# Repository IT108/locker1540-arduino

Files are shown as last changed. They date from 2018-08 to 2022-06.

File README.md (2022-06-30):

# Система контроля и управления доступом
## Проект в школе ОРТ 1540 

<ins>Амеличев Константин, Парамонов Дмитрий, под руководством Скибицкого Романа Марковича</ins>

Состоит из нескольких компонент:

* Ардуино-контролер, использующийся для управления различными модулями
* RFID сканер карточек (коридор)
* Трехцветный светодиод для индикации состояния сканера (коридор)
* Кнопка звонка (коридор)
* Электромагнитный замок
* Датчики состояния двери (открыта/закрыта, герконы)
* Пьезоэлемент для звука звонка в дверь
* Кнопка открытия двери изнутри кабинета
* Датчики движения в кабинете
* Источник бесперебойного питания
* Реле для управления освещением
* Внешняя индикация для кабинета охраны
* Веб-сервер на Raspberry Pi, хранящий базу данных о пришедших пользователях
* Динамик для персональных приветствий

### Функционал:

* Вход в кабинет по корректным карточкам
* Аудиоприветствие вошедшего человека (например, "Добрый день, Роман"). Конструируется случайно, дополнительно учитывая время суток
* Мониторинг наличия людей в кабинете, выключение света при отсутствии людей
* Кнопка звонка, играющая мелодию из "Звездных войн"
* Отправка состояния системы на индикационную панель охранника

## Фотографии, схемы:

Одна из версий платы:
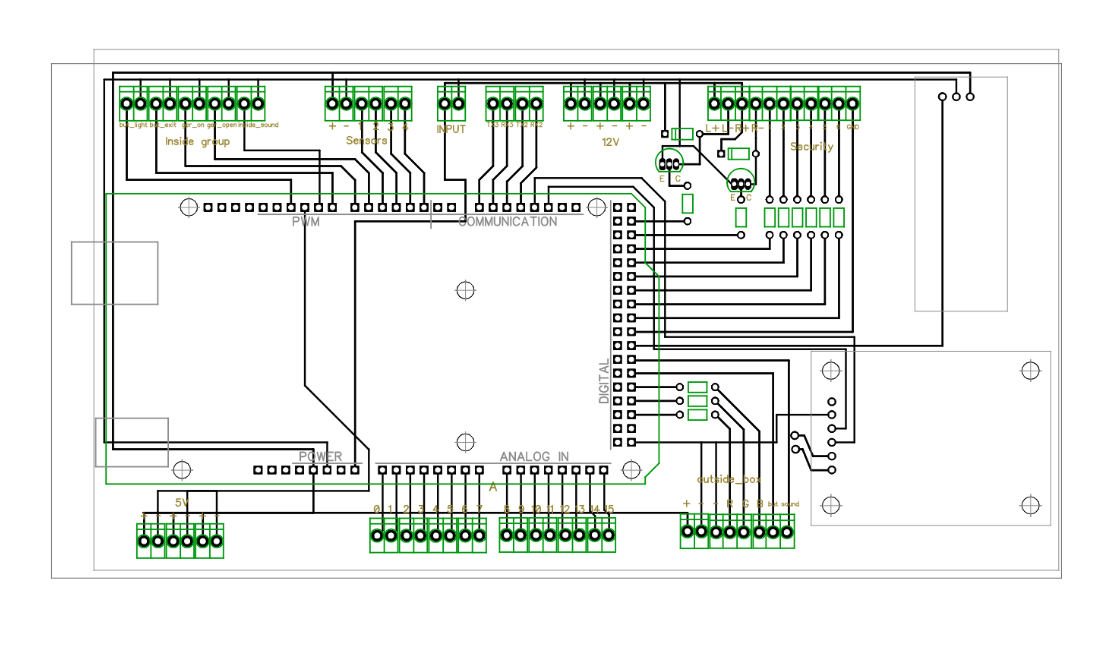
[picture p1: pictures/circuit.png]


Физическая спаянная плата с Arduino и реле
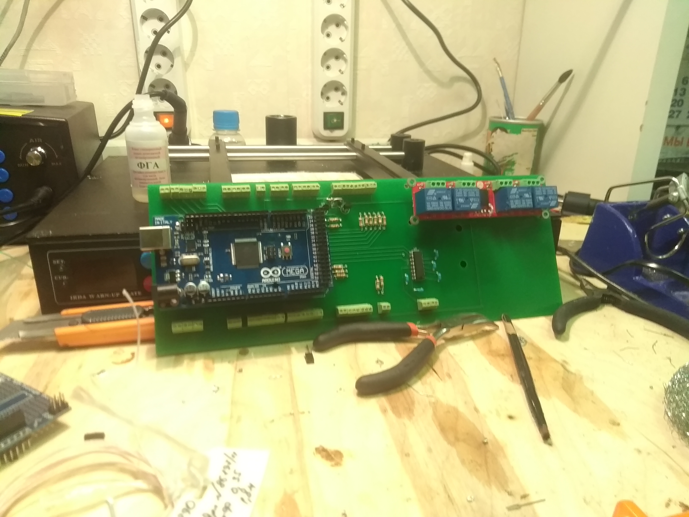
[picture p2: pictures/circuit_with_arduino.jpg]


Демонстрация зеленого светодиода при прикладывании нужной карты
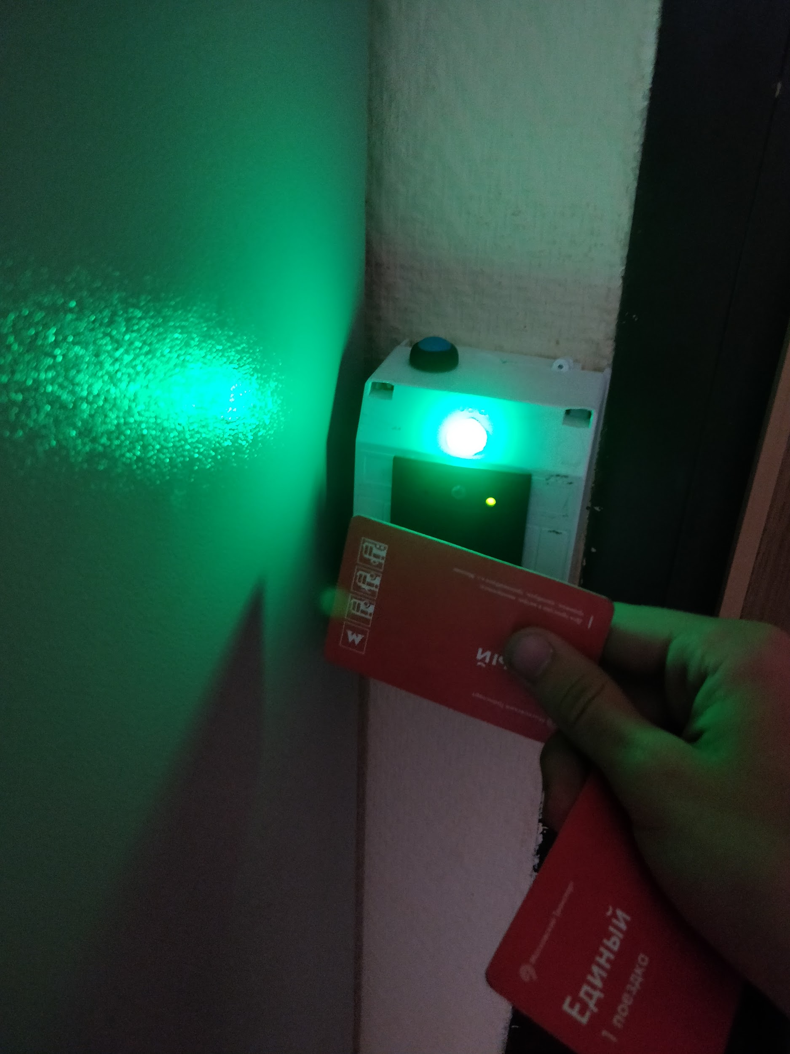
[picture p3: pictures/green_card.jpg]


Интеграция в кабинет до 2018 года (без собственной платы, arduino + COM-shield)
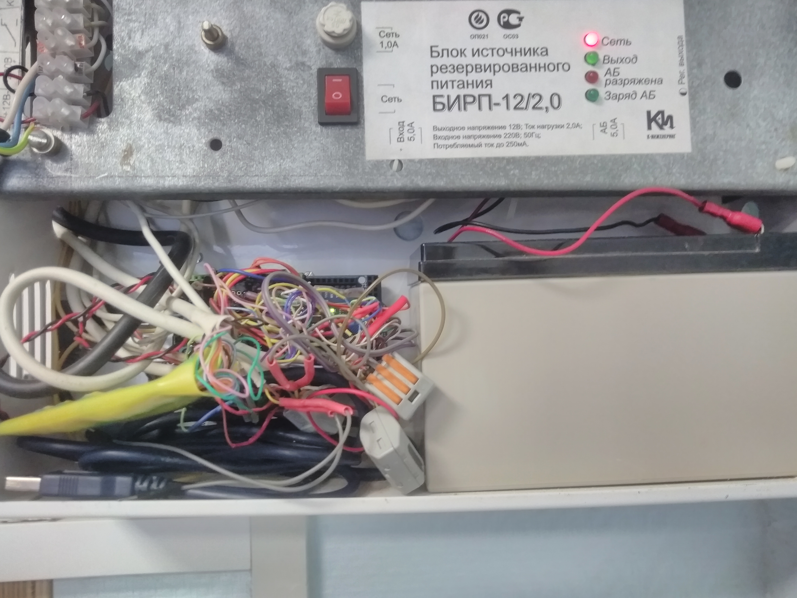
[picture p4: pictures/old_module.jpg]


Интеграция в кабинет 2018/2019 года (а собственной платой, arduino + RS232-модуль + реле) 
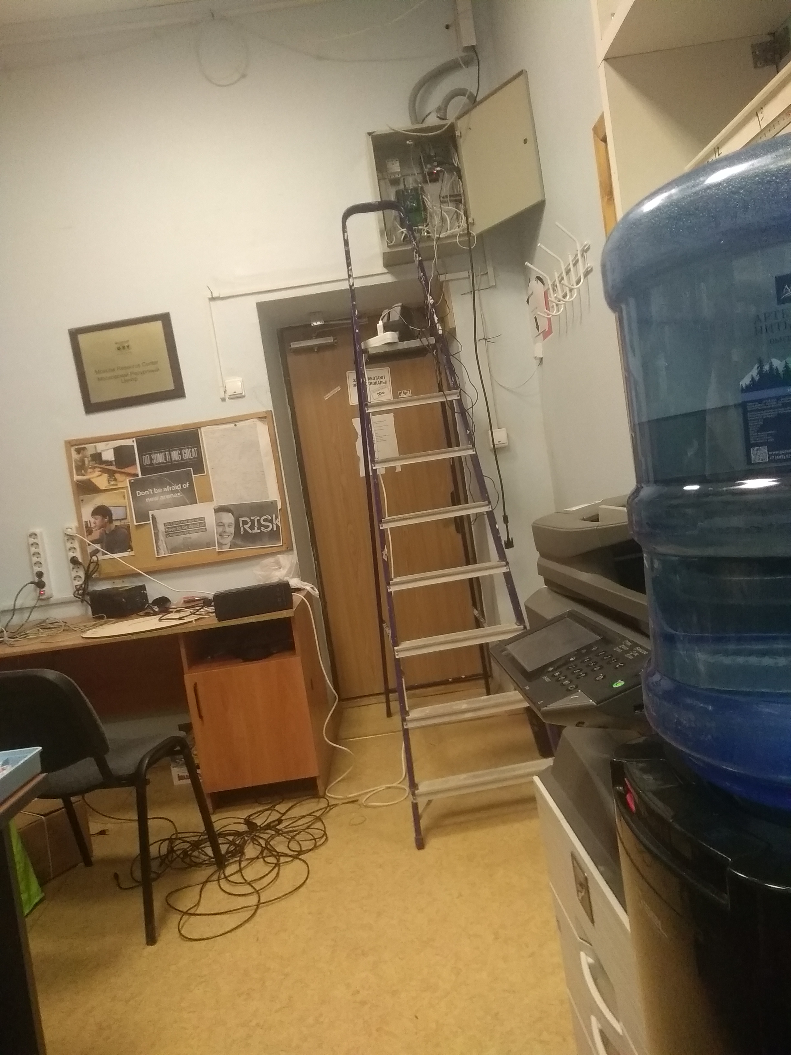
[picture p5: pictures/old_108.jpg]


Интеграция в кабинет с 2019/2020 учебного года


## Интересные документы:
* Текст проектной работы по мотивам проекта [link](МГК%20ЗАМОК%202019.pdf)
* Необходимые детали для сбора аналогичной платы [link](schemes/Список%20покупок%20для%20новой%20платы.xlsx)
* Схема соединений между блоками системы [link](schemes/locker108scheme.pdf)

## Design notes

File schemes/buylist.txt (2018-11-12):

что надо купить

Шкаф для хранения системы
Raspberry Pi для сервера
ИБП компактный

тезисы - 
сверху ставим Din, на который крепим автомат, raspberry pi
внизу ставим большой ups
По центру ставим еще один din, на который повесим плату
Надо тянуть один провод ethernet

https://videoglaz.ru/elektromontazhnye-shkafy-i-schity/ruself/ruself-schmp-06-ip31

https://www.moxa.ru/shop/accessories/mounting/dk35a/

https://www.etm.ru/cat/nn/9724561/ х2

http://amperka.ru/collection/bestsellers/product/raspberry-pi-3-model-b-plus

http://lartmaster.ru/goods/Plastikovye-derzhateli-dlya-DIN-rejki

https://www.dns-shop.ru/product/940e53a73bcf3330/ibp-dexp-iec-450va/characteristics/

https://on.pleer.ru/product_219638_Sven_Special_Base_5_Sockets_05m.html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

Вариант 2 http://www.mean-well.ru/store/DRC-60A/

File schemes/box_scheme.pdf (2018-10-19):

автомат arduino + raspberry pi

2ая din- рейка

UPS

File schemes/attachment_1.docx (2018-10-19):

Инструкция по открытию двери

С левой стороны от двери находится считыватель карт.

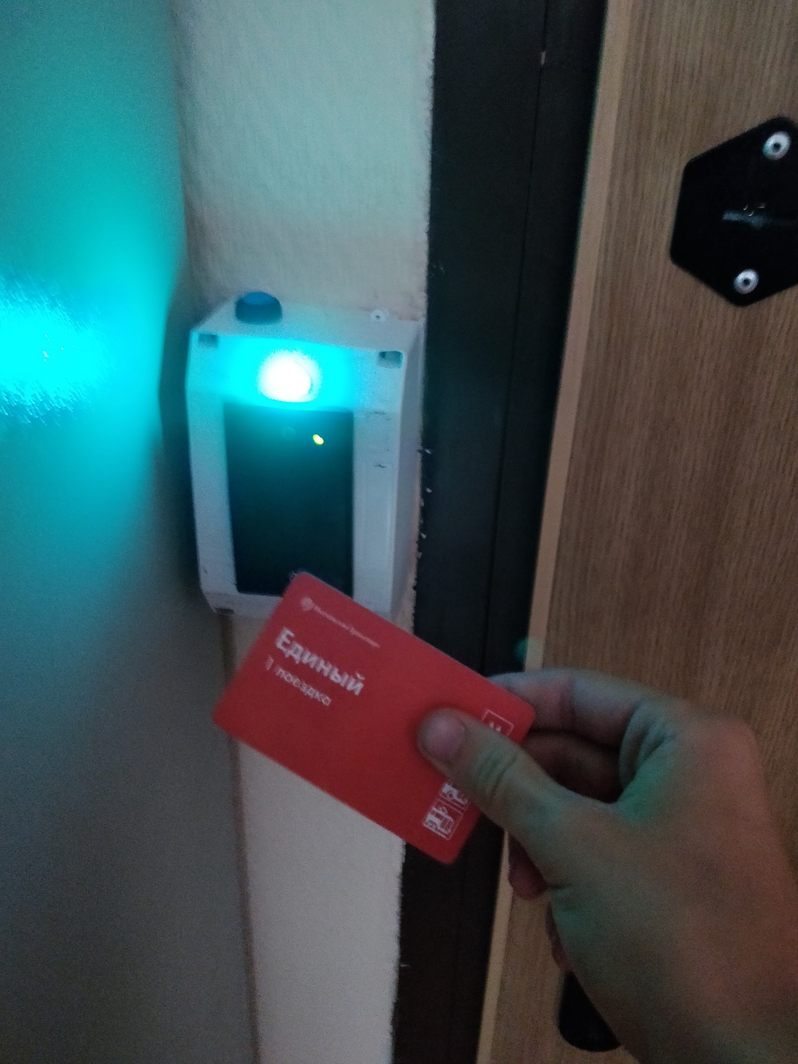
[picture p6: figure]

Для того, чтобы открыть дверь, надо приложить свою карту к считывателю и дождаться звукового сигнала, который означает, что карта считалась. Далее возможно несколько ситуаций, которые зависят от того, есть ли карточка в базе данных(допущена к входу) или нет.

1. Карточка есть в базе данных. Тогда светодиод над считывателем загорается зеленым цветом и дверь открывается.


2. Карточки нет в базе данных. Тогда светодиод над считывателем загорается красным цветом.

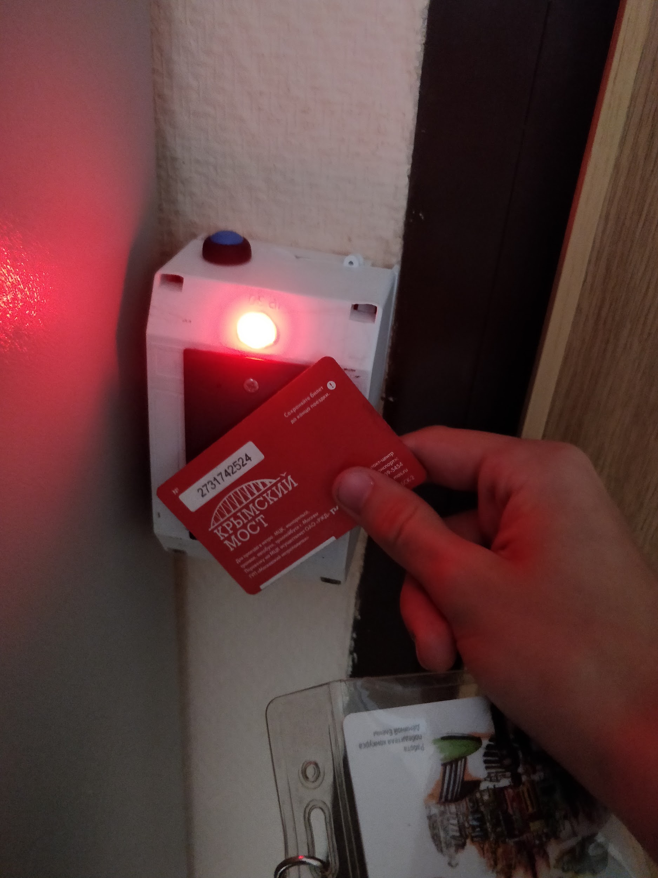
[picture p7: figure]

3. Карточка является мастер-картой. Тогда светодиод над считывателем загорается синим цветом.

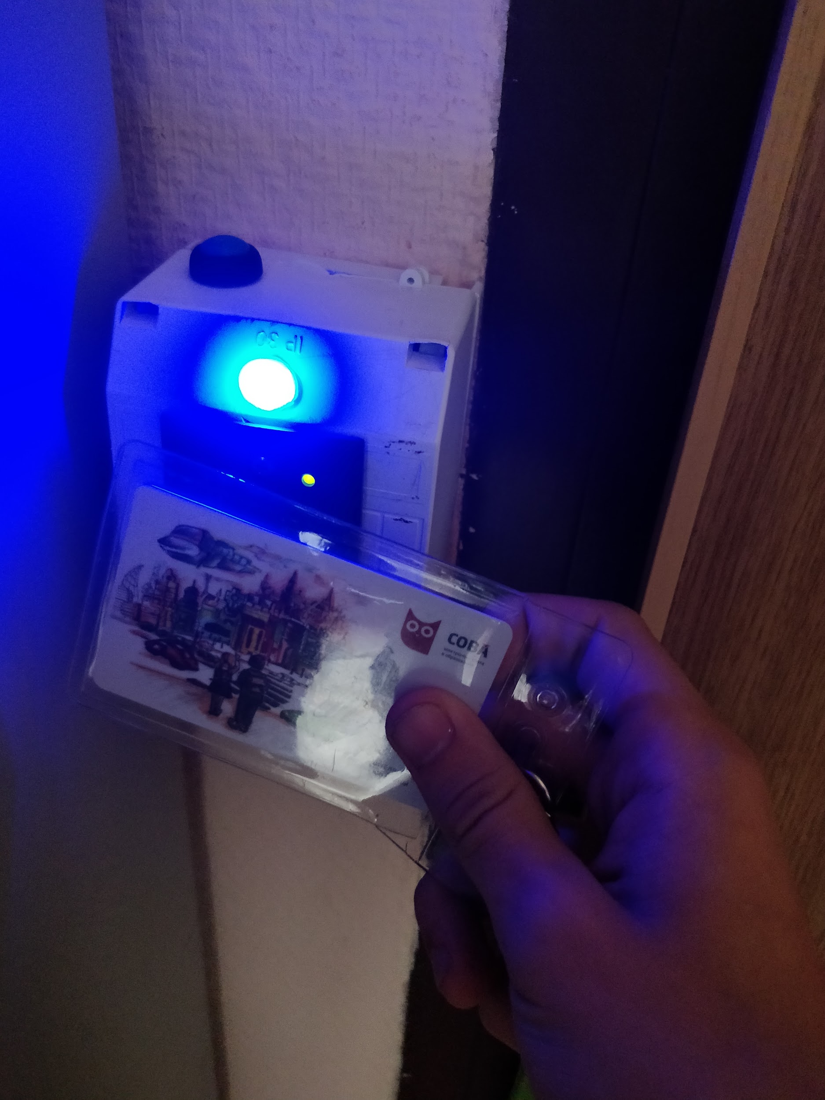
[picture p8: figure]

Для того, чтобы выйти из кабинета, надо нажать на кнопку выхода, расположенную с правой стороны относительно двери.

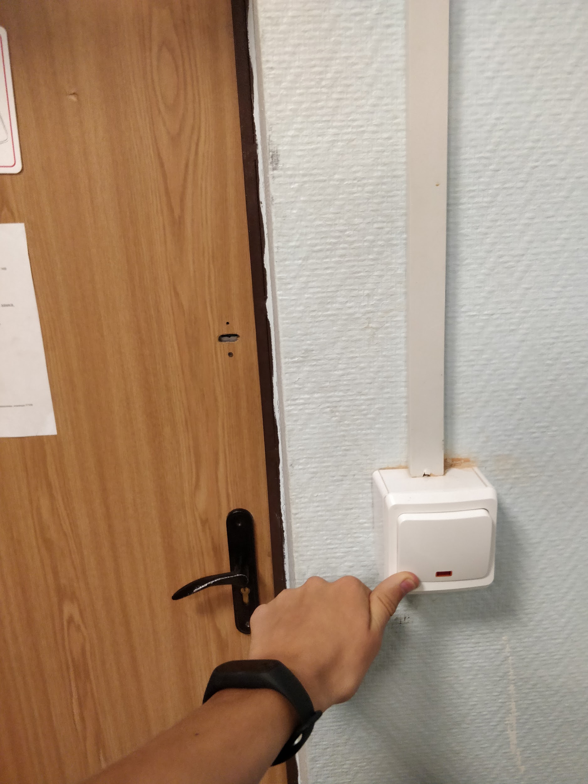
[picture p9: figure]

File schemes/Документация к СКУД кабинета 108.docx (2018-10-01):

Документация к СКУД кабинета 108

1. Функционал системы
  1) Вход-выход из кабинета
  2) Система работы с ключ-картами
  3) Функционал на вахте
  4) Музыкальная шкатулка
2. Физическая часть
  1) Основной блок
    a. Управляющий контроллер
    b. Плата управлением питания системы
  2) Перечень внешних блоков
  3) Соединение внешних блоков
  4) Запирающее устройство
  5) Система электропитания
3. Софтверная часть
  1) Контроллер замка
  2) Веб-сервер
4. Приложение

Функционал системы

Вход-выход из кабинета

В режиме ожидания дверь кабинета находится в закрытом состоянии. Вход в кабинет осуществляется с помощью ключ-карты. Для выхода из кабинета необходимо воспользоваться возвратным выключателем внутри кабинета. В случае, если у поситителя нет доступа в кабинет, он может воспользоваться кнопкой звонка. [ТУДУ. Полноценная инструкция по использованию модуля «дверь» находится в Приложение 1(Инструкция по входу-выходу из кабинета). При возникновении внештатных ситуаций в кабинет можно попасть, воспользовавшись инструкцией из Приложение 2(Инструкция по аварийному открытию кабинета)]

Система работы с ключ-картами

Для аунтификации используются ключ-карты, соответствующие стандарту Mifare RFID. Для модификации списка людей с доступом в кабинет можно использовать приложение или мастер-карту. При использовании приложения предоставляется возможность дополнять учетную запись дополнительными параметрами(ФИО, приветствие итд), поэтому такой способ является предпочтительным. Для моментального добавления учетной записи воспользуйтесь мастер-картой. При добавлении учетной записи с помощью мастер-карты рекомендуется дополнительно установить параметры учетной записи через приложение.

[ТУДУ. Для изменения базы допущенных людей пользуйтесь Приложение 3. Инструкция по добавлению-удалению людей c помощью веб-консоли. или Приложение 4. Инструкция по добавлению-удалению людей с помощью мастер-карты]

Функционал на вахте

Для осуществления контроля состояния кабинета сотрудниками службы безопасности предусмотрена мониторинговая система, которая позволяет отслеживать:

1. Отсутствие людей в кабинете – зеленая индикация соответствует пустому кабинету, а красная – наличию людей.
2. Состояние двери – зеленая индикация соответствует закрытой двери, а красная - открытой.
3. Состояние защелки – зеленая индикация соответствует катушке защелки под напряжением, а красная – обесточенной.

Музыкальная шкатулка

Система имеет возможность проигрывать аудиофайлы, загруженные в память. В данный момент эта функция используется для проигрывания приветствия при входе пользователя в кабинет. Управление устройством осуществляется с платы веб-сервера. Для создания персонализированного приветствия предусмотрен отдельный функционал. [ТУДУ. Приложение 5. Инструкция по работе с аудиофайлами]

Физическая часть

Основной блок

Управляющий контроллер

В качестве основного контроллера используется Arduino Mega ADK. Дополнительно на нее установлен RS232 Shield для взаимодействия со считывателем ключ-карт.

К основному контроллеру подсоединены:

1. Внешний модуль «Считыватель»
2. Внешний модуль «Замок», имеется размыкатель питания в модуле «Считыватель»
3. Внешний модуль «Веб-сервер»
4. Модуль «Звонок», расположенный в основном блоке
5. Внешние модули «Датчики движения»
6. Внешний модуль «Мониторинговая система»
7. Внешний модуль «Кнопка выхода»
8. Внешний модуль «Герконы»

[ТУДУ. Для обновления прошивки используется USB type B, расположенный на управляющем контроллере. Инструкция по обновлению прошивки находится в Приложении 6. Инструкция по обновлению прошивки микроконтроллера]

Система управления питанием

СУП представлена распаянными на макетной плате(расположенной на RS232 Shield’е) элементами управления питанием внешнего блока «Замок». Также с ее помощью организовано питание управляющего контроллера, и к ней подключены модуль «Кнопка выхода» и RGB светодиод из модуля «Считыватель». Дополнительно на макетной плате распаяны вспомогательные сопротивления. [ТУДУ. Схема СУП’а расположена в Приложении 7. Схема макетной платы].

Перечень внешних блоков

1. Считыватель. Блок «Считыватель» содержит считыватель ключ-карты, пьезоизлучатель, индикаторный RGB светодиод, кнопку звонка. Также есть возможность открыть крышку блока шлицевой отверткой и разомкнуть схему питания блока «Замок».
2. Замок. Блок «Замок» содержит защелку электромеханическую «ШЕРИФ-1 премиум». Защелка потребляет 12В. Управление прямое – при подаче напряжения защелка закрывает дверь.
3. Герконы. Блок «Герконы» встроен в защелку электромеханическую «ШЕРИФ-1 премиум». Он содержит два магнитных датчика, отвечающих за мониторинг состояния защелки – один замыкается в случае, если ригель в защелке(дверь закрыта), второй замыкается, если на защелку подано электропитание.
4. Датчики движения. Блок «Датчики движения» состоит из четырех датчиков движения – трех инфракрасных и одного микроволнового. С их помощью система проверяет наличие людей в кабинете. [ТУДУ. Схема расположения датчиков находится в Приложении 8. Расположение датчиков движения]
5. Мониторинговая система. Этот блок расположен в пункте охраны и оборудован несколькими индикационными светодиодами.
6. Кнопка выхода. Блок «Кнопка выхода» находится под основным блоком и состоит из возвратного выключателя, с помощью которого происходит открытие двери изнутри.
7. Звонок. Модуль «Звонок» состоит из пьезоизлучателя, который приклеен на верхнюю крышку основного блока и используется для сигнала звонка.
8. Веб-сервер. Блок «Веб-сервер» используется для хранения базы данных, обработке запросов на добавление-удаление ключ-карт из системы, хранения и обработки приветствий для музыкальной шкатулки.
9. Динамик. Блок «Динамик» находится под блоком «Веб-сервер» и используется для проигрывания аудиофайлов, пришедших с блока «Веб-сервер».

[ТУДУ. Схема взаимодействия блоков находится в Приложение 9. Блок-схема]

Соединение внешних блоков

Все провода, выходящие из основного блока, промаркированы. [ТУДУ. В Приложении 10. «Нумерация проводов», можно посмотреть соответствие блоков и проводов]

1. Считыватель. К блоку «Считыватель» идет набор проводов, которые проходят через отверстие в стене под блоком «Кнопка выхода». В этот набор входит провод питания от блока «Замок», витая пара, содержащая сигнальные провода и провода питания.
2. Замок. К блоку «Замок» напрямую идет один провод, а второй идет в него через блок «Считыватель»
3. Герконы. К блоку «Герконы» идут 4 провода – два провода заведены на землю, два провода воткнуты в управляющий микроконтроллер.
4. Датчики движения. Из Основного блока выходят 4 провода для передачи сигнала и два провода питания. В распаечной коробке питание разделяется на 4 ветки и дальше выходят 4 ветки по 3 провода в каждой – 2 на питание и 1 на сигнал.
5. Мониторинговая система. К блоку «Мониторинговая система» идет витая пара, содержащая общую землю, шесть сигналов (красный и зеленый сигнал для трех светодиодов), один провод свободен – на него возможна установка кнопки. Также в основном блоке подвешена заизолированная плата с сопротивлениями для шести сигнальных проводов.
6. Кнопка выхода. К «Кнопке выхода» идет четыре провода – два провода питания, два других оставлены для возможности дальнейших улучшений.
7. Звонок. К модулю «Звонок» идет четыре провода, из которых используются два провода питания.
8. Веб-сервер. К блоку «Веб-сервер» идет 4 провода – Rx, Tx, два провода на питание.
9. Динамик. К блоку «Динамик» идет два провода питания.

Программная часть

Контроллер замка.

Код контроллера замка написан для Arduino Mega ADK. В нем используется сторонняя библиотека FlexiTimer2, необходимая для работы с прерываниями.

Код разбит на несколько модулей:

1. Обработчик карт «handler»
2. Внешний светодиод «outside_led»
3. Клиентская часть для связи с сервером «client»
4. Обработка данных для сотрудников охраны «security»
5. Кнопка выхода «exit_button»
6. Модуль дверного звонка «door_bell»
7. Модуль для работы с защелкой «locker»
8. Модуль для хранения номеров входов и выходов контроллера(пинов) «constant_pins»

Принцип работы основной программы — в основном цикле обрабатывать данные с карт, работать с светодиодом, кнопкой выхода, звонком, получать данные с сервера. В прерываниях программа обновляет мониторинговую систему и цвет свтодиода.

Карта записывается в памяти набором из 8 чисел, каждое из которых — номер ASCII символа. Хранится в памяти идентификатор(ID) карты, записанный в 16-ичной системе счисления. В случае, если ID содержит больше, чем 8 символов, то оставшиеся символы игнорируются. Также, в силу особенностей считывателя, карта поступает в формате 78563412 относительно обычного считывателя(где цифра — позиция символа), и в таком формате она хранится в системе. Есть небольшой набор заранее заданных карт и мастер-карта, хранящихся непосредственно в коде. Основная база данных хранится на сервере, к которому обращается контроллер после прочтения карты.

Веб-сервер.

Приложение

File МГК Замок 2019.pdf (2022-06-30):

ДЕПАРТАМЕНТ ОБРАЗОВАНИЯ ГОРОДА МОСКВЫ ГОСУДАРСТВЕННОЕ БЮДЖЕТНОЕ ОБРАЗОВАТЕЛЬНОЕ УЧРЕЖДЕНИЕ ГОРОДА МОСКВЫ
«ШКОЛА №1540»

ПРОЕКТНАЯ РАБОТА

# Умный класс

СОЗДАНИЕ ИНТЕЛЛЕКТУАЛЬНОЙ СИСТЕМЫ ДЛЯ КОНТРОЛЯ ДОСТУПА И УПРАВЛЕНИЯ КАБИНЕТОМ

Научный руководитель:
Скибицкий Роман Маркович

Оглавление

Оглавление | 1
Аннотация | 2
Введение | 2
Цели | 3
Актуальность | 3
Обзор литературы | 4
План работы над проектом | 4
Ресурсное обеспечение проекта | 6
Описание проекта | 7
Оценка полученного результата | 7
Выводы | 8

Аннотация

Проект «Умный класс» предполагает разработку и установку комплекса, автоматизирующего управление светом в кабинете, а также управляющего контролем доступа в кабинет. Данное решение упрощает доступ в кабинеты-лаборатории для авторизованных учащихся и персонала школы. Каждый авторизованный пользователь имеет при себе личный ключ, что упрощает ведение списков входа, также система в реальном времени предоставляет данные о кабинете и состоянии замка на пункт охраны. Также проект включает в себя автоматическое управление светом для снижения потребления электроэнергии и повышения удобства использования кабинета.

Введение

В первую очередь данная система разрабатывалась для контроля доступа в помещение. Комплекс предназначен для установки в кабинет-лабораторию, в которой хранится большое количество дорогостоящего оборудования. Необходимо было обеспечить его сохранность. В классе занимаются несколько различных групп учащихся, поэтому использование единственного ключа, хранящегося в пункте охраны, было бы неудобно. Для решения данной проблемы было предложено разработать систему управления и контроля доступа (далее -СКУД). Дверь в кабинет удерживается электромагнитным замком, а вместо ключа используются личные карты учащихся и учителей. Для хранения и редактирования информации о пользователях и их карточках был настроен веб-сервер и разработана консоль управления. До введения СКУД на пункте охраны была информация о наличии людей в кабинете, так как в школе ведется журнал выдачи ключей, работа с таким бумажным журналом была неудобна для отслеживания наличия кого-либо в кабинете, также подобная информация не всегда достоверна. Так как ключ-карта есть у каждого авторизованного пользователя и не хранится на охране, то журнал учета не отражал настоящую информацию о состоянии кабинета. Для решения данной проблемы в кабинет были установлены датчики движения, а на охране была установлена информационная панель. На основе этой информации мы также установили подсистему автоматического управления освещением в кабинете.

Организации

- Школа 1540 - предоставление оборудования, площадка для тестирования
- ниту МИСиС - производство печатных плат

Команда проекта

- Амеличев Константин, Школа 1540, работа над главным контроллером, монтажные работы
- Парамонов Дмитрий, Школа 1540, работа над веб-сервером, монтажные работы
- Скибицкий Роман Маркович, научный руководитель

Цели

- Разработать СКУД решение для удобного доступа в кабинет авторизованных пользователей и редактирования списка пользователей администратором.
- Обеспечить пункт охраны достоверной информацией о наличии людей в кабинете.
- Настроить систему для работы с минимальной поддержкой и профилактикой.

Актуальность

Данный проект был собран из подручных материалов и требовал минимальное число дополнительных ресурсов. Также консоль управления не загромождена, удобна, адаптирована для просмотра на мобильных устройствах и интуитивно понятна. (Написать что-нибудь про статистику)

Анализ существующих решений

Подобные системы встречаются у многих производителей, отличительной чертой нашего проекта является сравнительно низкая стоимость, открытый исходный код и возможность расширения системы дополнительными модулями. Также, так как одна из целей проекта -образовательная, было решено создать новую систему, а не использовать имеющуюся на рынке.

Обзор литературы

Основными источниками информации во время работы над проектом были следующие ресурсы о работе с Arduino:

arduino.cc/
wiki.amperka.ru/

План работы над проектом

Мы пользовались циклической системой работы над проектом -постепенно улучшали существующий продукт, выполняя проектирование, реализацию, тестирование и внедрение. Самая первая реализация проекта управляла замком и обрабатывала карточки, предусматривала кнопку для выхода из кабинета, бесперебойное питание замка. Перед созданием первой версии продукта были проведены разработка и тестирование каждой из подсистем по отдельности. При работе над второй версией были сделаны изменения, касающиеся датчиков движения - их установка, обработка, и вывод результатов на охрану. Также была внедрена функция дверного звонка для неавторизованных пользователей. Третьим этапом работ был перенос данных из памяти микроконтроллера на веб-сервер. После этого этапа у нас появилась возможность добавить опциональный функционал - в версии 3.5 мы внедрили голосовое приветствие вошедшего в кабинет. В последней на нынешний момент, 4ой реализации проекта, внедрен модуль управления освещением. В пятой версии мы планируем перекомпоновать все аппаратные модули системы и изменить конфигурацию системы для повышения отказоустойчивости решения и удобства его обслуживания.

этап работы | даты
Начало работы над проектом | ноябрь 2016
Разработка отдельных модулей | ноябрь 2016 - март 2017
Разработка прототипа | март 2017 - апрель 2017
Начало монтажных работ | апрель 2017 - сентябрь 2017
Тестирование и доработка прототипа | сентябрь 2017 - ноябрь 2017
Первая рабочая версия проекта | ноябрь 2017
Вторая рабочая версия проекта (монтаж системы оповещения охраны, дверной звонок) | ноябрь 2017 - январь 2018
Тестирование и доработка | январь 2018 - март 2018
Разработка локального сервера | апрель 2018 - сентябрь 2018
Разработка веб-сервера | сентябрь 2018
Третья рабочая версия проекта | октябрь 2018
Внедрение звуковых приветствий | октябрь 2018
Разработка системы автоматического контроля освещением и ее тестирование | ноябрь 2018
Четвертая рабочая версия проекта | декабрь 2018

Ресурсное обеспечение проекта

Основными компонентами нашей системы до обновления являются:
1. Электромагнитный замок
2. Источник бесперебойного питания с аккумулятором
3. Arduino Mega ADK с RS232 Shield в качестве главного микроконтроллера замка
4. Arduino Mega 2560 с Ethernet Shield в качестве контроллера для связи с веб-сервером
5. Динамик для аудиоприветствия
6. Дифференциальный автомат, обеспечивающий безопасное отключение системы при критических ошибках питания
7. Кнопка выхода
8. Информационная панель на охране
9. Внешний блок для считывателя ключ-карт, индикации, дверного звонка
После обновления:
1. Электромагнитный замок
2. Источник бесперебойного питания
3. Основная плата с установленной Arduino mega 2650
4. Дифференциальный автомат, обеспечивающий безопасное отключение системы при критических ошибках питания
5. Кнопка выхода
6. Информационная панель на охране
7. Внешний блок для считывателя ключ-карт, индикации, дверного звонка
8. Raspberry Pi, на которой будет настроен веб-сервер
После обновления системы количество аппартаных модулей изменится, а наиболее неустойчивые будут заменены, так Arduino mega с ethernet shield изменится на raspberry pi, которая сможет поддерживать веб-сервер и загружать скетчи в основной контроллер, на данный момент скетчи можно загрузить только с физическим доступом к плате. Также главная плата Arduino mega заменится печатной платой собственного производства на которой будет установлена Arduino, это сделано для более удобного подключения всех периферийных устройств и их питания.

Описание проекта

Основным блоком является контроллер замка, проводящий основные операции с замком, считывателем, датчиками, кнопками, светодиодами, пищалками и так далее. В качестве микроконтроллера выступает arduino mega adk с rs232 shield. Блок считывателя карт находится с наружней стороны кабинета, кроме непосредственно считывателя в нем находится индикационный светодиод, пищалка, кнопка звонка. Считыватель подключается по протоколу RS232. На информационной панели у охраны находятся 6 светодиодов - 3 пары “зеленый - красный”, которые передают информацию о состоянии двери, замка, кабинета (открыта ли дверь, работает ли замок, есть ли люди в кабинете). Данные о двери и замке система получает с герконов, установленных непосредственно в защелке замка. Информацию о заполненности кабинета система получает с помощью комбинации данных о двери и с датчиков присутствия, расположенных на потолке кабинета. Так как замок потребляет большой ток и работает от напряжения 12В (Arduino выдает только 5В), то для управления им используется транзисторная схема (управление большими токами с помощью малых). Для управления освещением используется реле, так как напряжение на лампах - 220В. Внешний блок сервера содержит микроконтроллер Arduino Mega 2560 с ethernet shield, через который осуществляется связь с базой данных, а также sd-карту, на которой хранятся аудиофайлы для приветствия. Для проигрывания аудио используется динамик и плата-переходник.
Оценка полученного результата

Данная система СКУД используется в нашей школе уже на протяжении года. За последние полгода количество ошибок, критически влиявших на работу системы, было минимально. Решение показало себя наилучшим из всех возможных, ведь с его помощью удалось минимизировать время, необходимое на открытие кабинета, до 3-4 секунд (в большинстве случаев быстрее чем открытие ключем).
Выводы

Данная система СКУД нуждается в некоторой доработке, но уже является полноценным продуктом. За время работы над проектом мы познакомились с основными принципами работы устройств СКУД, усовершенствовали свои навыки разработки под Arduino, веб-серверы, базы данных. Также мы научились основным принципам монтажных работ.

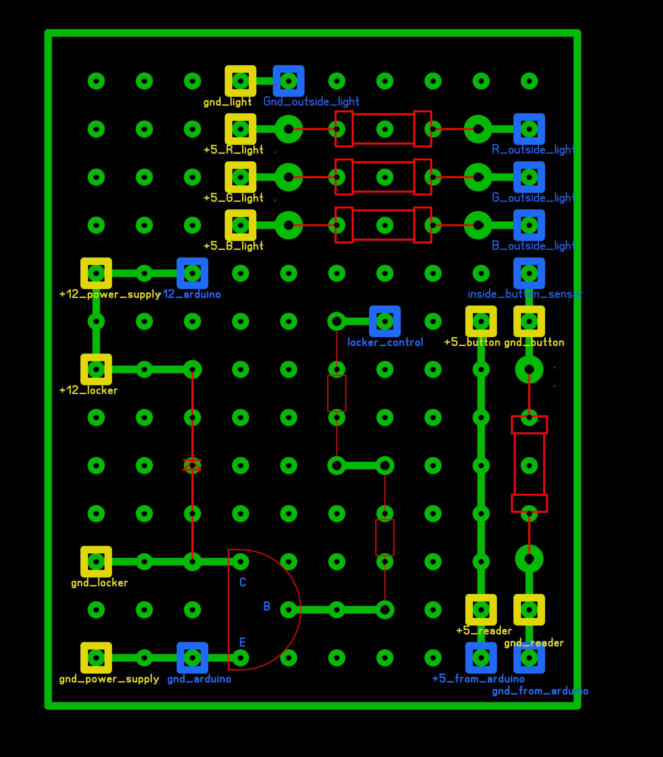
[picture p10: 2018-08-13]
schemes/kek.JPG

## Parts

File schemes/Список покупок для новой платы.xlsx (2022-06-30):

id | Элемент на плате | Наименования | Параметры | Ссылка | Сколько стоит | Примечание
1 | R1 | CF-25 (С1-4) | 350 ом | https://www.chipdip.ru/product0/9662 | 2 | На базу транзистора
2 | R2 | CF-25 (С1-4) | 350 ом | https://www.chipdip.ru/product0/9662 | 2 | На базу транзистора
3 | R3 | CF-25 (С1-4) | 1 ком | https://www.chipdip.ru/product0/44435 | 2 | Делитель сигнализация общее
4 | R4 | CF-25 (С1-4) | 5.1 ком | https://www.chipdip.ru/product0/51972 | 2 | Делитель сигнализация 24V
5 | R5 | CF-25 (С1-4) | 2 ком | https://www.chipdip.ru/product0/31521 | 2 | Делитель сигнализации 12V
6 | R6 | CF-25 (С1-4) | 1 ком | https://www.chipdip.ru/product0/44435 | 2 | R (внешняя коробка)
7 | R7 | CF-25 (С1-4) | 1 ком | https://www.chipdip.ru/product0/44435 | 2 | G (внешняя коробка)
8 | R8 | CF-25 (С1-4) | 1 ком | https://www.chipdip.ru/product0/44435 | 2 | B (внешняя коробка)
9 | R9 | CF-25 (С1-4) | 1 ком | https://www.chipdip.ru/product0/44435 | 2 | Свободный пин
10 | R10 | CF-100 (С1-4) | 560 ом | https://www.chipdip.ru/product0/59729 | 2 | Свободный пин
11 | R11 | CF-25 (С1-4) | 1 ком | https://www.chipdip.ru/product0/44435 | 2 | Светодиоды охрана
12 | R12 | CF-25 (С1-4) | 1 ком | https://www.chipdip.ru/product0/44435 | 2 | Светодиоды охрана
13 | R13 | CF-25 (С1-4) | 1 ком | https://www.chipdip.ru/product0/44435 | 2 | Светодиоды охрана
14 | R14 | CF-25 (С1-4) | 1 ком | https://www.chipdip.ru/product0/44435 | 2 | Светодиоды охрана
15 | R15 | CF-25 (С1-4) | 1 ком | https://www.chipdip.ru/product0/44435 | 2 | Светодиоды охрана
16 | R16 | CF-25 (С1-4) | 1 ком | https://www.chipdip.ru/product0/44435 | 2 | Светодиоды охрана
17 | R17 | CF-100 (С1-4) | 560 ом | https://www.chipdip.ru/product0/59729 | 2 | Лампочка ОРТ (ну зачеееееееееем)
18 | VT1 | КТ961А | коэф 40, 80V, 1.5 А 12.5Вт | https://www.chipdip.ru/product/kt961a-integral | 21 | Транзисторы для выходов 12 V
19 | VT2 | КТ961А | коэф 40, 80V, 1.5 А 12.5Вт | https://www.chipdip.ru/product/kt961a-integral | 21 | Транзисторы для выходов 12V
20 | VD1 | 1N5399 | 1.5A | https://www.chipdip.ru/product/1n5399 | 4 | Диод для выходов 12V
21 | VD2 | 1N5399 | 1.5A | https://www.chipdip.ru/product/1n5399 | 4 | Диод для выходов 12V
22 | C1 | ECAP (К50-35 мини) | 1мкф 25V | https://www.chipdip.ru/product0/9000261758 | 5 | Конденсаторы для MX232
23 | C2 | ECAP (К50-35 мини) | 1мкф 25V | https://www.chipdip.ru/product0/9000261758 | 5 | Конденсаторы для MX232
24 | C3 | ECAP (К50-35 мини) | 1мкф 25V | https://www.chipdip.ru/product0/9000261758 | 5 | Конденсаторы для MX232
25 | C4 | ECAP (К50-35 мини) | 1мкф 25V | https://www.chipdip.ru/product0/9000261758 | 5 | Конденсаторы для MX232
26 | C5 | ECAP (К50-35 мини) | 1мкф 25V | https://www.chipdip.ru/product0/9000261758 | 5 | Конденсаторы для MX232
27 | LED1 | GNL-3012HD | красный | https://www.chipdip.ru/product/gnl-3012hd | 5 | Светодиод ОРТ (ну зачеееем)
28 | DD1 | MAX232CPE | Питание 5V | https://www.chipdip.ru/product/max232cpe | 25 | MX232
29 | ARDUINO | Магония(Arduino Mega) | Питание 7-40V | https://www.chipdip.ru/product/magonija-2 | 1210 | ARDUINO!!!!!
30 | RELAY MODULE | RDC1-4RA Relay | 4 канала, 5V | https://www.chipdip.ru/product/rdc1-4ra-relay | 520 | Релейный модуль
31 | Двойной порт | DG300-5.0-03P-12 |  | https://www.chipdip.ru/product/dg300-5.0-02p-12 | 9 | Сколько-то штук! | 35
32 | Тройной порт | DG300-5.0-02P-12 |  | https://www.chipdip.ru/product/dg300-5.0-03p-12 | 12 |  | 7
33 | Pin extender | DS1023-30 1x10 for Arduino (PBS10) | 10 штук | https://www.chipdip.ru/product/ds1023-30-1x10-for-arduino | 25 |  | 6
34 | Pin extender | DS1023-30 1x8 | 8 штук | https://www.chipdip.ru/product/ds1023-30-1x8-for-arduino | 19 |  | 10
35 | Гнездо на плату | DS1023-1*4 S01 (PBS-4*) (PBS-04*) | 4 ножки | https://www.chipdip.ru/product/ds1023-1-4-s01-pbs-4-pbs-04 | 0.8 |  | 2
36 | Гнездо на плату | DS1023-01-1*10 SF11 | 10 ножек | https://www.chipdip.ru/product/ds1023-01-1-10-sf11 | 6 |  | 2
37 | Гнездо на плату | PBD-36 (DS1023-2X18) | 2х9 | https://www.chipdip.ru/product/pbd-36 | 19 |  | 1
38 | Гнездо на плату | PBS-8 (DS-1023 -1x 8) | 8 ножек | https://www.chipdip.ru/product/pbs-8 | 7 |  | 7
 |  |  |  |  | 2853.72

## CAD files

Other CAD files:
schemes/компоновка шкаф.dwg

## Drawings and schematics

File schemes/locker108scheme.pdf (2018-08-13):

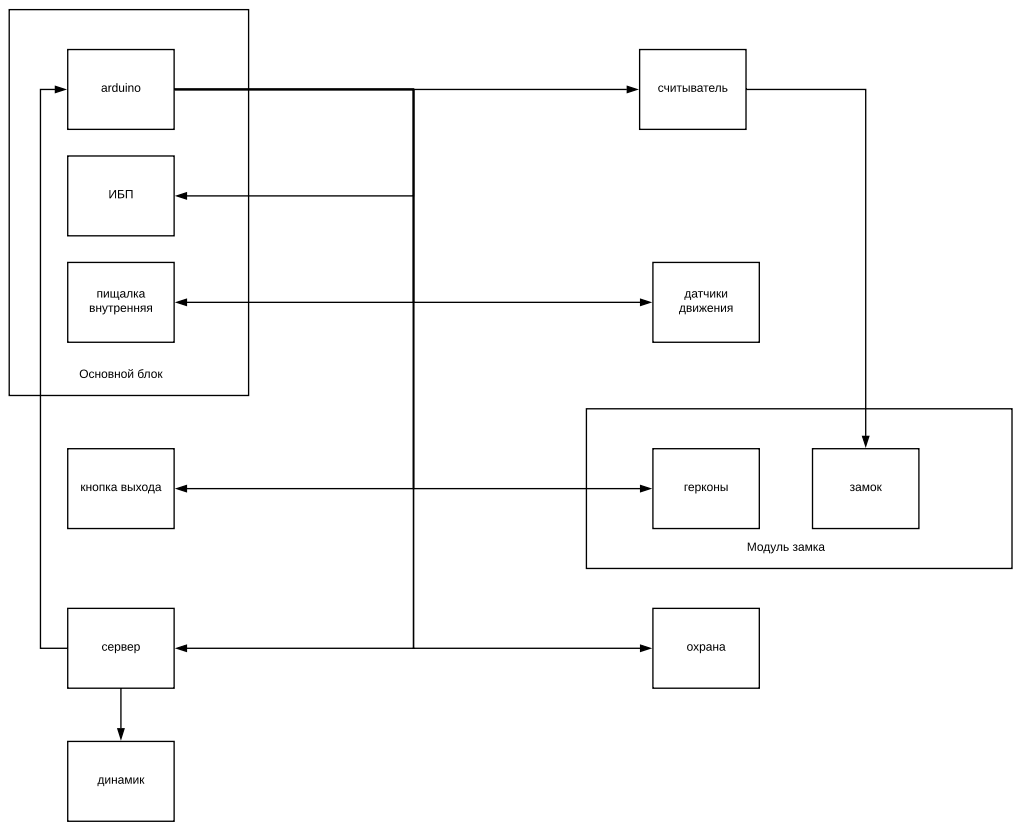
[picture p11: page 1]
arduino

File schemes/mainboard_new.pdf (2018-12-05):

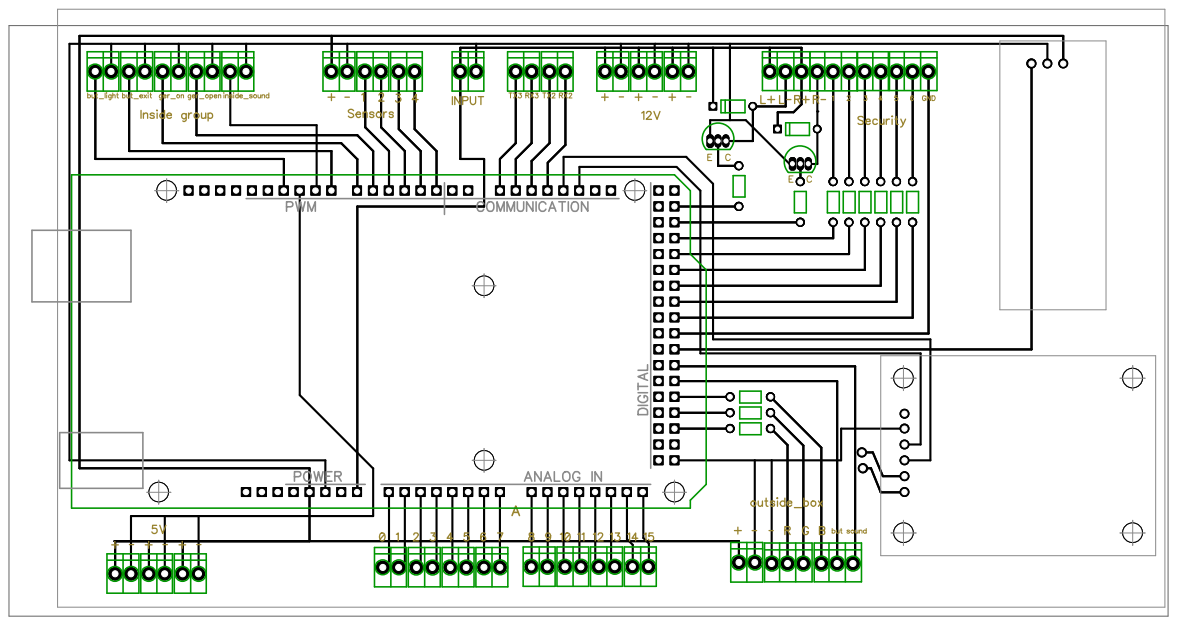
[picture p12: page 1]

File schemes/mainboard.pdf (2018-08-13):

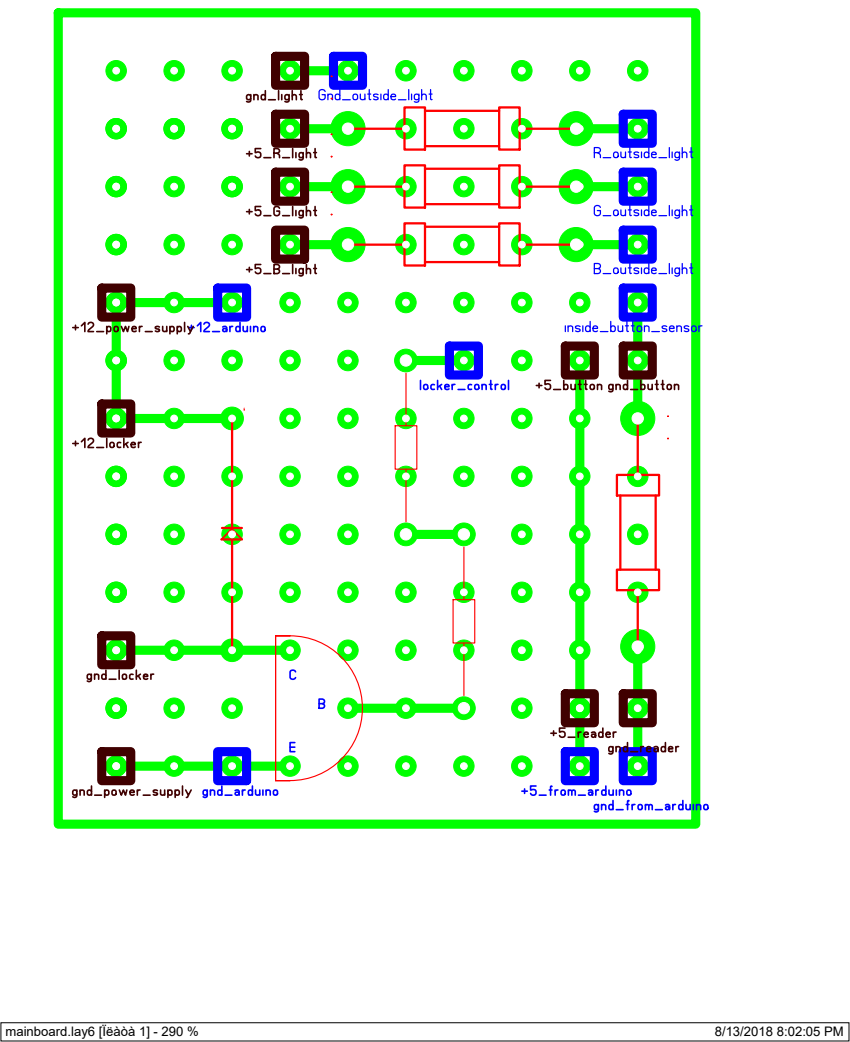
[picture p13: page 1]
mainboard.lay6 [Ïëàòà 1] - 290 %

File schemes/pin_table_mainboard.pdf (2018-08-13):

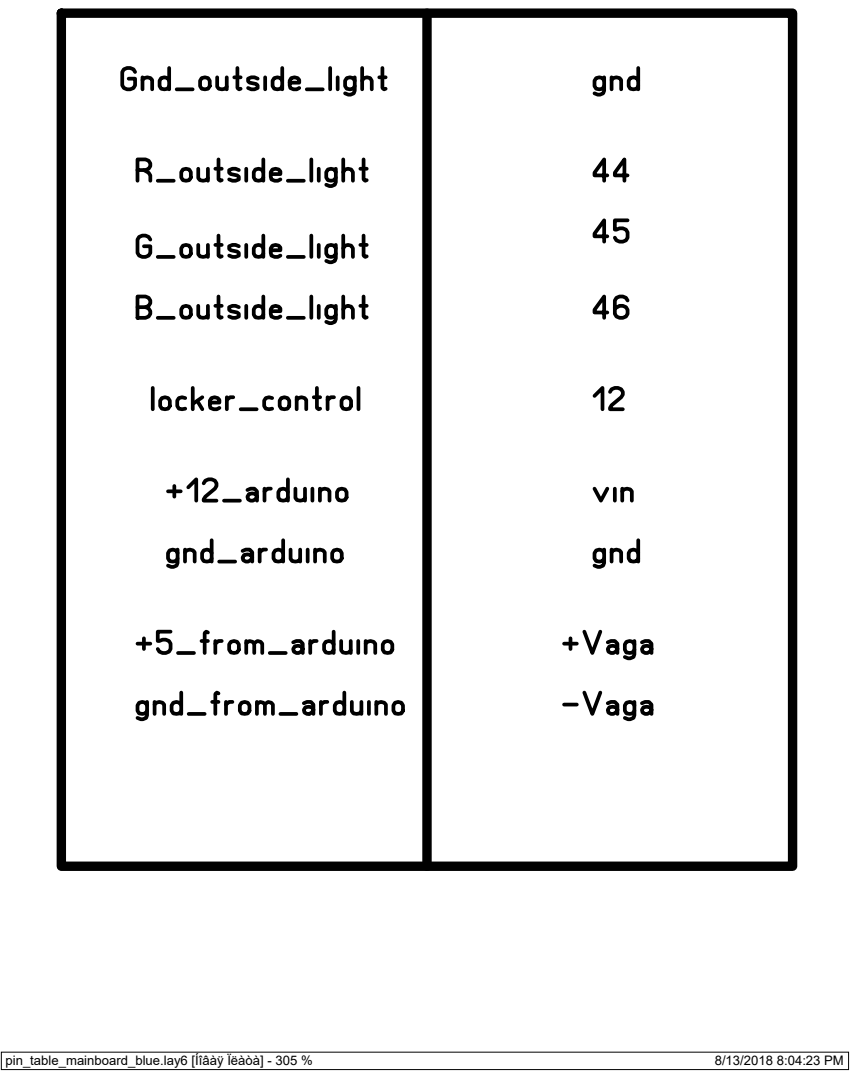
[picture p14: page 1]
pin_table_mainboard_blue.lay6 [Íîâàÿ Ïëàòà] - 305 %

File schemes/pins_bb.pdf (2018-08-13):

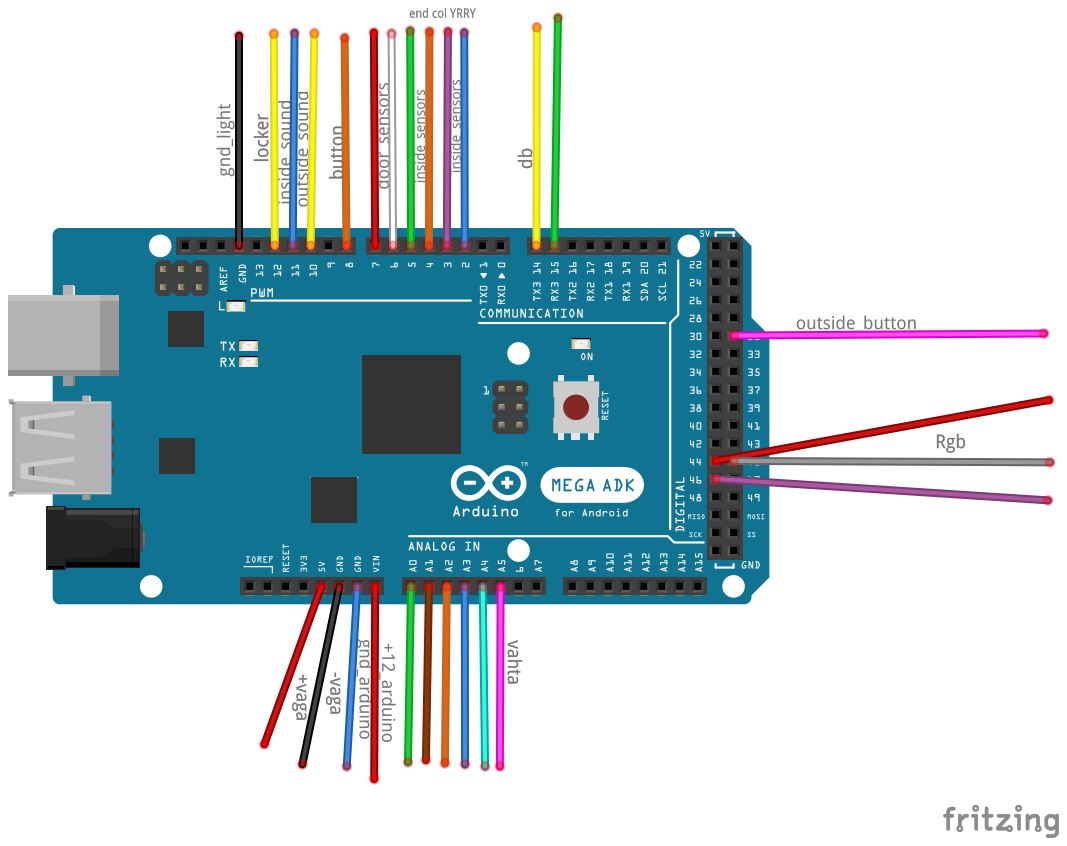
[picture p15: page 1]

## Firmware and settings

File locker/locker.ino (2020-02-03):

#include <FlexiTimer2.h>
#include <QueueArray.h>

struct Event {
  long long timer;
  int value;
  Event() {
    timer = 0;
    value = 0;
  }
  Event(long long a, int b) {
    timer = a, value = b;
  }
};

struct Pin {
  int pin = -1;
  int type = -1;
  int rev = 0;

  Pin() {
    pin = -1;
    type = -1;
    rev = 0;
  }

  Pin(int a, int b, int c = 0) {
    pin = a, type = b;
    if (c) {
      rev = 1;
    }
    set_mode();
    if (c == 1) {
      write(1, 'f');
    }
  }

  void set_mode() {
    pinMode(pin, type);
  }

  int read() {
    if (type != INPUT) {
      return 0;
    }
    return digitalRead(pin) ^ rev;
  }

  void write(int x, char c = 'x') {
    if (type != OUTPUT && c != 'f') {
      return;
    }
    return digitalWrite(pin, x);
  }

  void analog(int x) {
    if (type != OUTPUT) {
      return;
    }
    return analogWrite(pin, x);   
  }

  void tone(int a, int b) {
    ::tone(pin, a, b);
  }

  void no_tone() {
    noTone(pin);
  }
};

struct Timer {
  long long value;
  int need_to_check;

  Timer() {}
  Timer(int x = 0) {
    need_to_check = x;
    value = millis();
  }

  void set(long long x) {
    value = x;
  }

  void update() {
    value = millis();
  }

  void check() {
    if (value > millis()) {
      update();
    }
  }

  long long get() {
    if (need_to_check) {
      check();
    }
    return value;
  }

  long long diff(long long x = -1) {
    if (x == -1) {
      x = millis();
    }
    return abs(value - x);
  }

  bool already_past() {
    return value < millis();
  }
};

namespace constant_pins {
  const int V_MEN_R = 29;
  const int V_MEN_G = 27;
  const int V_DOOR_R = 31;
  const int V_DOOR_G = 33;
  const int V_LOCKER_R = 35;
  const int V_LOCKER_G = 37;

  const int OUTSIDE_BUTTON = 53;
  const int OUTSIDE_RED = 44;
  const int OUTSIDE_GREEN = 45;
  const int OUTSIDE_BLUE = 46;

  const int LOCKER = 36;

  const int SOUND_OUTSIDE = 43;
  const int SOUND_INSIDE = 9;

  const int DOOR_SENSOR = 6;
  const int LOCKER_SENSOR = 7;
  const int EXIT_BUTTON = A0;

  const int INSIDE_SENSOR_0_0 = 2;
  const int INSIDE_SENSOR_0_1 = 3;
  const int INSIDE_SENSOR_1_0 = 4;
  const int INSIDE_SENSOR_1_1 = 5;
  const int LIGHT_BUTTON = A1;

  const int RELAY_0 = 36;
  const int RELAY_1 = 34;
  const int RELAY_2 = 32;
  const int RELAY_3 = 30;

}

namespace constant_values {
  const long long DELAY_SECOND = 1000;
  const long long DELAY_TWO_SECONDS = 2 * DELAY_SECOND;
  const long long DELAY_THREE_SECONDS = 3 * DELAY_SECOND;
  const long long DELAY_FIVE_SECONDS = 5 * DELAY_SECOND;
  const long long DELAY_MINUTE = 60000;
  const long long DELAY_FIVE_MINUTES = 5 * DELAY_MINUTE;
  const long long DELAY_HALF_AN_HOUR = DELAY_MINUTE * 30;
  const long long DELAY_HOUR = DELAY_MINUTE * 60;
  const long long DELAY_GREEN = DELAY_FIVE_SECONDS;
  const long long DELAY_RED = DELAY_TWO_SECONDS;
  const long long DELAY_BLUE = DELAY_TWO_SECONDS;
  const int CARD_SIZE = 8;
}

namespace door_bell {
  const int COUNT_NOTES = 9;
  const int WAITING_DELAY = constant_values::DELAY_FIVE_SECONDS;
  const int BEEP_FREQUENCE = 1000;
  const int BEEP_LENGTH = 150;
  const Pin OUTSIDE_BUTTON(constant_pins::OUTSIDE_BUTTON, INPUT, 1);
  const Pin SOUND_INSIDE(constant_pins::SOUND_INSIDE, OUTPUT);
  const Timer TIMER(0);

  const int FREQUENCES[COUNT_NOTES] = {
    392, 392, 392, 311, 466, 392, 311, 466, 392
  };
  const int DURATIONS[COUNT_NOTES] = {
    350, 350, 350, 250, 100, 350, 250, 100, 700
  };

  void play() {
    TIMER.check();
    if (!OUTSIDE_BUTTON.read() || TIMER.diff() < WAITING_DELAY) {
      return;
    }
    for (int i = 0; i < COUNT_NOTES; i++) {
      SOUND_INSIDE.tone(FREQUENCES[i], DURATIONS[i]);
      delay(DURATIONS[i]);
    }
    SOUND_INSIDE.no_tone();
    TIMER.update();
  }

  void beep() {
    SOUND_INSIDE.tone(BEEP_FREQUENCE, BEEP_LENGTH);
    delay(BEEP_LENGTH);
    SOUND_INSIDE.no_tone();
  }
}

namespace outside_led {
  const int RED_COLORS[] = {255, 0, 0};
  const int GREEN_COLORS[] = {0, 255, 0};
  const int BLUE_COLORS[] = {0, 0, 255};
  const int YELLOW_COLORS[] = {255, 255, 0};
  int current_red = 255;
  int current_green = 0;
  int current_blue = 0;
  const Timer TIMER(0);
  const Pin RED(constant_pins::OUTSIDE_RED, OUTPUT);
  const Pin GREEN(constant_pins::OUTSIDE_GREEN, OUTPUT);
  const Pin BLUE(constant_pins::OUTSIDE_BLUE, OUTPUT);

  void led(int red, int green, int blue) {
    if (!TIMER.already_past()) {
      return;
    }
    RED.analog(red);
    GREEN.analog(green);
    BLUE.analog(blue);
  }

  void add_time(long long t) {
    TIMER.set(max(TIMER.get(), millis() + t));
  }

  void led_current() {
    led(current_red, current_green, current_blue);
  }

  void red() {
    led(RED_COLORS[0], RED_COLORS[1], RED_COLORS[2]);
  }
 
  void green() {
    led(GREEN_COLORS[0], GREEN_COLORS[1], GREEN_COLORS[2]);
  }

  void yellow() {
    led(YELLOW_COLORS[0], YELLOW_COLORS[1], YELLOW_COLORS[2]);
  }

  void blue() {
    led(BLUE_COLORS[0], BLUE_COLORS[1], BLUE_COLORS[2]);
  }

  void recolor() {
    if (current_red > 0 && current_blue == 0) {
      current_red--;
      current_green++;
    }
    else if (current_green > 0) {
      current_green--;
      current_blue++;
    }
    else if (current_blue > 0) {
      current_blue--;
      current_red++;
    }
  }
}

namespace security {
  extern const Timer TIMER;
  extern const Timer LAST_OPEN_TIMER;
  extern long long cabinet_balance;
  void decrease();
  void increase();
}

namespace inside_light {
  extern const long long DELAY_EMPTY;
  extern const long long DELAY_GAP;
  extern int is_button;
}

namespace locker {
  const int LOCK = 1;
  const int UNLOCK = 0;
  int door_closed = 0;
  const Timer TIMER(0);

  const Pin LOCKER(constant_pins::LOCKER, OUTPUT);
  const Pin DOOR_SENSOR(constant_pins::DOOR_SENSOR, INPUT, 1);
  const Pin LOCKER_SENSOR(constant_pins::LOCKER_SENSOR, INPUT, 1);

  void lock() {
    LOCKER.write(LOCK);
  }

  void unlock() {
    LOCKER.write(UNLOCK);
  }

  int locker_status() { // 1 for locker not working
    return !LOCKER_SENSOR.read();
  }

  int door_status() { // 1 for closed door
    int tmp = 1 ^ DOOR_SENSOR.read();
    if (tmp != door_closed) {
      door_closed = tmp;
      security::LAST_OPEN_TIMER.update();
    }
    return door_closed;
  }

  void add_time(long long add) {
    TIMER.set(max(TIMER.get(), millis() + add));
  }

  void update() {
    if (TIMER.already_past()) {
      lock();
    }
    else {
      unlock();
    }
  }
}

namespace exit_button {
  const Timer TIMER(0);
  int button_status = 0;
  int current_status = 0;
  const long long DELAY_WAIT = constant_values::DELAY_THREE_SECONDS;

  const Pin EXIT_BUTTON(constant_pins::EXIT_BUTTON, INPUT, 1);

  void check() {
    current_status = EXIT_BUTTON.read();
    if (current_status == 1 && button_status == 0) {
      if (door_bell::TIMER.diff() < constant_values::DELAY_MINUTE) {
        security::increase();
      }
      else {
        security::decrease();
      }
      locker::add_time(constant_values::DELAY_GREEN);
      outside_led::green();
      outside_led::add_time(constant_values::DELAY_GREEN);
      TIMER.update();
      door_bell::beep();
      button_status = 1;
      return;
    }
    if (current_status == 0 && TIMER.diff() > 100) {
      button_status = 0;
      return;
    }
    if (current_status == 1 && button_status == 1 && TIMER.diff() > DELAY_WAIT) {
      security::increase();
      outside_led::yellow();
      outside_led::add_time(constant_values::DELAY_FIVE_MINUTES);
      locker::add_time(constant_values::DELAY_FIVE_MINUTES);
      button_status = 2;
      door_bell::beep();
    }
    if (current_status == 1 && button_status == 2 && TIMER.diff() > 2 * DELAY_WAIT) {
      outside_led::yellow();
      outside_led::add_time(constant_values::DELAY_HALF_AN_HOUR);
      locker::add_time(constant_values::DELAY_HALF_AN_HOUR);
      button_status = 3;
      door_bell::beep();
    }
    if (current_status == 1 && button_status == 3 && TIMER.diff() > 3 * DELAY_WAIT) {
      outside_led::yellow();
      outside_led::add_time(constant_values::DELAY_HOUR);
      locker::add_time(constant_values::DELAY_HOUR);
      button_status = 4;
      door_bell::beep();
    }
    if (current_status == 1 && button_status == 4 && TIMER.diff() > 4 * DELAY_WAIT) {
      outside_led::TIMER.update();
      locker::TIMER.update();
      door_bell::beep();
      button_status = 0;
    }
  }
}

namespace security {
  long long cabinet_balance;
  const Timer TIMER(0);
  const Timer LAST_OPEN_TIMER(0);
  const long long DELAY_EMPTY = constant_values::DELAY_MINUTE;
  const long long DELAY_KILL = constant_values::DELAY_HALF_AN_HOUR;
  const long long DELAY_GAP = constant_values::DELAY_FIVE_SECONDS;
  QueueArray <Event> queue;

  const Pin MEN_R(constant_pins::V_MEN_R, OUTPUT);
  const Pin MEN_G(constant_pins::V_MEN_G, OUTPUT);
  const Pin DOOR_R(constant_pins::V_DOOR_R, OUTPUT);
  const Pin DOOR_G(constant_pins::V_DOOR_G, OUTPUT);
  const Pin LOCKER_R(constant_pins::V_LOCKER_R, OUTPUT);
  const Pin LOCKER_G(constant_pins::V_LOCKER_G, OUTPUT);

  const int SENSORS_SIZE = 4;
  const Pin SENSORS[SENSORS_SIZE] = {
    Pin(constant_pins::INSIDE_SENSOR_0_0, INPUT),
    Pin(constant_pins::INSIDE_SENSOR_0_1, INPUT),
    Pin(constant_pins::INSIDE_SENSOR_1_0, INPUT),
    Pin(constant_pins::INSIDE_SENSOR_1_1, INPUT)
  };


  void decrease() {
    queue.push(Event(millis() + DELAY_GAP * 2, -1));
  }

  void increase() {
    cabinet_balance++;
  }

  int cabinet_status() {
    bool status = 0;
    for (int i = 0; i < SENSORS_SIZE; i++) {
      status |= SENSORS[i].read();
    }
    TIMER.check();
    if (status) {
      TIMER.update();
    }
  }

  bool check_if_inside() {
    Timer current_timer(0);
    while (queue.count() && queue.front().timer < current_timer.get()) {
      cabinet_balance += queue.front().value;
      queue.pop();
    }
    if (cabinet_balance < 0) {
      cabinet_balance = 0;
    }
    if (TIMER.diff() < DELAY_GAP) {
      cabinet_balance = max(cabinet_balance, 1);
    }
    if (TIMER.diff() > DELAY_KILL) {
      cabinet_balance = 0;
      while (queue.count()) {
        queue.pop();
      }
    }
    return cabinet_balance > 0;
  }

  void red(Pin R, Pin G) {
    R.write(1);
    G.write(0);
  }

  void green(Pin R, Pin G) {
    R.write(0);
    G.write(1);
  }

  void update() {
    cabinet_status();
    if (!check_if_inside()) {
      green(MEN_R, MEN_G);
    }
    else {
      red(MEN_R, MEN_G);
    }
    if (locker::door_status()) {
      green(DOOR_R, DOOR_G);
    }
    else {
      red(DOOR_R, DOOR_G);
    }
    if (locker::locker_status()) {
      green(LOCKER_R, LOCKER_G);
    }
    else {
      red(LOCKER_R, LOCKER_G);
    }
  }
}

namespace inside_light {
  bool automatic_mode = true;
  int is_button = 0;
  int status = 0;
  const Timer TIMER(0);
  const long long DELAY_EMPTY = constant_values::DELAY_MINUTE;
  const long long DELAY_GAP = constant_values::DELAY_FIVE_SECONDS;

  const Pin LIGHT_BUTTON(constant_pins::LIGHT_BUTTON, INPUT, 1);
  const Pin EMPTY_RELAYS[] = {
    Pin(constant_pins::RELAY_0, OUTPUT),
    Pin(constant_pins::RELAY_1, OUTPUT),
    Pin(constant_pins::RELAY_2, OUTPUT),
    Pin(constant_pins::RELAY_3, OUTPUT),
  };
  const Pin INSIDE_LIGHT = EMPTY_RELAYS[1];

  void check_button() {
    if (LIGHT_BUTTON.read()) {
      is_button ^= 1;
      TIMER.update();
    }
  }

  void light() {
    if (status == 1) {
      return;
    }
    if (!automatic_mode) {
      return;
    }
    INSIDE_LIGHT.write(1);
    status = 1;
  }

  void unlight() {
    if (status == 0) {
      return;
    }
    if (!automatic_mode) {
      return;
    }
    INSIDE_LIGHT.write(0);
    status = 0;
  }

  void update() {
    if (TIMER.diff() < constant_values::DELAY_SECOND) {
      return;
    }
    check_button();
    if (is_button) {
      unlight();
      return;
    }
    if (security::check_if_inside()) {
      light();
    }
    else {
      unlight();
    }
  }
}

namespace logger {
  void card();
  void send_status();
}

namespace client {
  const String GREETING = "play_greet";
  const String CHECK = "check_card";

  const int RESPONSE_OPEN = 89;
  const int RESPONSE_CLOSE = 78;
  const int RESPONSE_LIGHT_ON = 91;
  const int RESPONSE_LIGHT_AUTO = 92;
  const int RESPONSE_LIGHT_OFF = 93;
  const int RESPONSE_STATUS = 83;


  String make_request(String operation, int card[]) {
    String res = "[" + operation + "]";
    res += "card:";
    for (int i = 0; i < constant_values::CARD_SIZE; i++) {
      res += (char)card[i];
    }
    res += "\r\n";
    return res;
  }

  void greeting(int card[]) {
    Serial.print(make_request(GREETING, card));
  }

  void check(int card[]) {
    Serial.print(make_request(CHECK, card));
  }

  void receive() {
    if (Serial.available()) {
      int ans = Serial.read();
      if (ans == RESPONSE_OPEN) {
        security::increase();
        outside_led::green();
        outside_led::add_time(constant_values::DELAY_GREEN);
        locker::add_time(constant_values::DELAY_GREEN);
      }
      if (ans == RESPONSE_CLOSE) {
        outside_led::red();
        outside_led::add_time(constant_values::DELAY_RED);
      }
      if (ans == RESPONSE_LIGHT_ON) {
        inside_light::light();
        inside_light::automatic_mode = false;
      }
      if (ans == RESPONSE_LIGHT_AUTO) {
        inside_light::automatic_mode = true;
        inside_light::unlight();
      }
      if (ans == RESPONSE_LIGHT_OFF) {
        inside_light::unlight();
        inside_light::automatic_mode = false;
      }
      if (ans == RESPONSE_STATUS) {
        logger::send_status();
      }
    }
  }
}


namespace handler {
  const int CARD_SIZE = 8;
  const int MASTER_CARD[CARD_SIZE] = {
    55, 57, 55, 57, 48, 55, 55, 57
  }; //0 -> 48
  const int BAD_SYMBOLS_SIZE = 9;
  const int BAD_SYMBOLS[BAD_SYMBOLS_SIZE] = {
    -1, 2, 3, 10, 13, 249, 191, 235, 0
  };
  const int LOCAL_DB_SIZE = 4;
  const int DEFINED_CARDS[LOCAL_DB_SIZE][CARD_SIZE] = {
    {66, 66, 57, 53, 65, 53, 66, 54},  // Vahta
    {69, 54, 57, 55, 49, 69, 70, 57},  // Paramonov
    {68, 57, 53, 52, 48, 57, 52, 57},  // Amelichev
    {68, 57, 52, 49, 69, 51, 52, 57},   // Filippov
  };

  // 0  1  2  3  4  5  6  7  8  9  A  B  C  D  E  F
  // 48 49 50 51 52 53 54 55 56 57 65 66 67 68 69 70
  int position = 0;
  int buffer[CARD_SIZE];

  bool check_card(int a[], int b[]) {
    for (int i = 0; i < constant_values::CARD_SIZE; i++) {
      if (a[i] != b[i]) {
        return false;
      }
    }
    return true;
  }

  bool is_valid(int a) {
    for (int i = 0; i < BAD_SYMBOLS_SIZE; i++) {
      if (a == BAD_SYMBOLS[i]) {
        return false;
      }
    }
    return true;
  }

  void handle_card(int card[]) {
    bool ok = false;
    logger::card();
    for (int i = 0; i < LOCAL_DB_SIZE; i++) {
      ok = check_card(DEFINED_CARDS[i], card);
      if (ok) {
        client::greeting(card);
        locker::add_time(constant_values::DELAY_GREEN);
        outside_led::green();
        outside_led::add_time(constant_values::DELAY_GREEN);
        security::increase();
        return;
      }
    }
    client::check(card);
  }

  void read() {
    int value = Serial1.read();
    if (!Serial1.available()) {
      position = 0;
      return;
    }
    if (is_valid(value)) {
      buffer[position++] = value;
      if (position == constant_values::CARD_SIZE) {
        handle_card(handler::buffer);
        position = 0;
      }
    }
  }
}

namespace radio {
  const Timer TIMER(0);
  const long long DELAY_GAP = constant_values::DELAY_THREE_SECONDS;

  void send(char x, char y) {
    if (TIMER.diff() < DELAY_GAP) {
      return;
    }
    Serial2.write(x * 10 + y);
    Serial2.write('\n');
    TIMER.update();
  }

  int receive() {
    if (!Serial2.available()) {
      return 0;
    }
    int x = Serial2.read();
    return x;
  }
};
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
void loop() {
  exit_button::check();
  outside_led::recolor();
  outside_led::led_current();
  client::receive();
  door_bell::play();
  handler::read();
  radio::send(0, security::cabinet_balance);
  delay(2);
}

/*
::::::::::::::::::::::::::::::::::::::::::::::::::::::::::::::::::::::::::::::::::::::::::::::::::::::
::::::::::::::::::::::::::::::::::::::::::::::::::::::::::::::::::::::::::::::::::::::::::::::::::::::
::::::::::::::::::::::::::::::::::::::::::::::::::::::::::::::::::::::::::::::::::::::::::::::::::::::
::::::::::::::::::::::::::::::::::::::::::::::::::::::::::::::::::::::::::::::::::::::::::::::::::::::
::::::::::::::::::::::::::::::::::::::::::::::::::::::::::::::::::::::::::::::::::::::::::::::::::::::
::::::::::::::::::::::::::::::::::::::::::::::::::::::::::::::::::::::::::::::::::::::::::::::::::::::
::::::::::::::::::::::::::::::::::::::::::::::::::::::::::::::::::::::::::::::::::::::::::::::::::::::
:::::::::::::::::::::::::::::::::^\.*+=%=%===================%%%=*-\^:::::::::::::::::::::::::::::::::
::::::::::::::::::::::::^%.*=%=========+=====*:-=++::=+:*==+=+===%======%=+-\^::::::::::::::::::::::::
:::::::::::::::::::%.*========*=+*=======+*=\\.+-:.\^*--=**+=+*:::%%% -*+=======+-\:::::::::::::::::::
:::::::::::::::\*====%===+.::::::^*==+*+=+:==++*+:+*+*+*^:::::::::::::::::::\+=+====%* ^::::::::::::::
:::::::::::^:===%==.\*:%^*\:::::::-=.\\+%:::\-::%==**:* :::::::&::::::&&:::::-+=*  *=====*%:::::::::::
::::::::^-=====.^:.*%:^* :::::::::::\%*%:::^%^::::*::: ::.=+^:::::::::::::::::::-:+*^:\+%===*^::::::::
::::::%=====\:::*-:::.-::::::::::*:^^=^:::: .:::\:%%.%==*=::^:::::::::::::::::%%%= %=*^::%===== ::::::
::::^+%+=*^:::\:::::::::::::::::^^:::^:::::::::::::::::::::::::::::::::::::::::::::::::::::: ====\::::
:::-%==::::::::::::::==========::::::::::::::::===========::::::::::::=================:::%^^^.===*^::
::*===%::::^+^:::::===============:::::::: .:::===============::: ::::=================::^-:::::*===^:
::==+^::::::::::::=================::::::::: ::======:::=======:::\*::=================:::-\::::::===:
%===%:::::\:::::======:::::::=======::::::+%:::======::::======:::^+^::::::=======::::::::^*:::::^*==:
+==*::::::. ::::=====:::::::::======::::::*%:::===============::::^+^::::::=======:::::::^:*^:::::-==:
+==+::::::. ::::=====:::::::::======:::\ :*%:::============::::::::=:::::::=======::::::::==^:::::-==:
^==%\:::::%*::::======:::::::=======:::::*+%:::======:=====:::::::^+:::::::=======::::::::==.::::^+==:
:-==+^:::::-\::::=================:::::::-- :::=====:::======:::::\::::::::=======::::::::%%:::::*==+:
:::===\:::::*\::::.==============:::::: :::::::======:::======:::::%:::::::=======::::::::.%:-%^+==+^:
:::.%==::::::::::::::=========:::::::::::::::::======::::=======::^:::::-::=======:::::::^=--.*%==::::
::::^*===*%:::^*%::::::::::::::::*^:.+\::::-::::::::::::::::::::::::::::^::::::::::::::-*\:-+===+%::::
::::::^*=%==::::%+%::::* :::::=\:::::+ :::: ::::::-^:::::^%^::::-\:::::..:::::*\:::^+*^ *======^::::::
::::::::: =====*^::+-::::+ ::::.*:^*=.: ::::=%::::-^:::::. :::::.::::%=%::::+ :::\+\:^-==+%=::::::::::
:::::::::::: +====%:\%*:%::.+%::::-:.++ -:::^:::::-^::::^*::::*%:::^+ ::: =\:^.+ %-======-::::::::::::
:::::::::::::::%-+=========+- -=: \.=-   *:  -+  \:    .+   *:   ** \.+* .*%=========:\:::::::::::::::
::::::::::::::::::::\-+%=======+::++.%-*.-+= :\:%.*-.::*:-^%%%%..\ *============: ^:::::::::::::::::::
:::::::::::::::::::::::::^\.*==============+====+******+++============%==+-\%:::::::::::::::::::::::::
::::::::::::::::::::::::::::::::::^%\.:*==%%%==========%%%%===+*- %^^:::::::::::::::::::::::::::::::::
::::::::::::::::::::::::::::::::::::::::::::::::::::::::::::::::::::::::::::::::::::::::::::::::::::::
::::::::::::::::::::::::::::::::::::::::::::::::::::::::::::::::::::::::::::::::::::::::::::::::::::::
::::::::::::::::::::::::::::::::::::::::::::::::::::::::::::::::::::::::::::::::::::::::::::::::::::::
::::::::::::::::::::::::::::::::::::::::::::::::::::::::::::::::::::::::::::::::::::::::::::::::::::::
::::::::::::::::::::::::::::::::::::::::::::::::::::::::::::::::::::::::::::::::::::::::::::::::::::::
::::::::::::::::::::::::::::::::::::::::::::::::::::::::::::::::::::::::::::::::::::::::::::::::::::::
::::::::::::::::::::::::::::::::::::::::::::::::::::::::::::::::::::::::::::::::::::::::::::::::::::::
*/

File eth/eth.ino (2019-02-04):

#include <stdint.h>
#include <Dhcp.h>
#include <Dns.h>
#include <Ethernet.h>
#include <EthernetClient.h>
#include <EthernetServer.h>
#include <EthernetUdp.h>
#include <DFPlayer_Mini_Mp3.h>
#include <QueueList.h>
#include <FlexiTimer2.h>

#include<SPI.h>
#include<SD.h>
#include<Ethernet.h>
#include <WString.h>
//Serial defines
#define LockerSerial Serial3
#define DebugSerial Serial
#define bufferMax 128
//Server variables
String pass = "12345";
byte mac[] = {0xA0, 0x20, 0xA6, 0x21, 0xBB, 0xF5};
IPAddress ip(192, 168, 1, 38);
EthernetServer server(80);
int keyLength = 6;
//System variables
const int PIN_DFPLAYER_BUSY = 24; // warning
bool debug = true;
int q[60][8];
int w[8];
int n;
int w2[8];
bool need_reset = false;
const int PIN_CHIP_SELECT = 22;
const int LIGHT_BTN = 8;
String cardsFileName = "CARDS.txt";
QueueList<int> greeting_buffer;
char buffer[bufferMax];

void reset(){
  digitalWrite(7, 0);
}

namespace local_db {

    void clear_db() {
        for (int i = 0; i < 60;i++) {
            for (int j = 0; j < 8; j++) {
                q[i][j] = 0;
            }
        }
    }

    void parse_cards_from_file() {
        int i = 0;
        int a;
        File cards = SD.open(cardsFileName);
        DebugSerial.println("Parsing cards...");
        if (cards) {
            while (cards.available()) {
                for (int f = 0; f < 8; f++) {
                    a = cards.read();
                    q[i][f] = a;

                    if (debug) {
                        DebugSerial.print(q[i][f]);
                        DebugSerial.print(" ");
                    }
                }
                i++;
                cards.seek(i * 10);
                if (debug) DebugSerial.println();
            }
            n = i;
        }
        cards.close();
    }

    bool check_card(int a[], int b[]) {
        for (int i = 0; i < 8; i++) {
            if (a[i] != b[i]) {
                return false;
            }
        }
        return true;
    }

    bool check_guest(int a[]) {
        for (int i = 0; i < 60; i++) {
            if (check_card(q[i], a)) {
                return true;
            }
        }
        return false;
    }
}


namespace DB {
    String server_answer = "";
    String guest_authorization = "";
    String request = "";
    String request_args = "";
    String request_page = "";
    byte db_server[] = {176, 99, 11, 114};
    String server = "176.99.11.114";
    String personal_greeting = "-1";
    String common_greeting = "-1";
    String post_data = "";

    void build_request() {
        String res = "POST /";
        res += request_page;
        res += " HTTP/1.1\r\nHost: ";
        res += server;
        res += "\r\nContent-Type: application/x-www-form-urlencoded\r\nContent-Length: ";
        res += String(request_args.length());
        res += "\r\n\r\n";
        res += request_args;
        request = res;

    }

    void get_post_data(){
        int data_start = server_answer.indexOf("\r\n\r\n") + 4;
        post_data = server_answer.substring(data_start);

    }


    void parse_guest_answer() {
        int data_start = server_answer.indexOf("\r\n\r\n") + 4;
        guest_authorization = server_answer.substring(data_start, 4);
        int common_greeting_start = server_answer.indexOf(";", data_start) + 1;
        int personal_greeting_start = server_answer.indexOf(";", common_greeting_start) + 1;
        int data_end = server_answer.indexOf(";", personal_greeting_start);
        guest_authorization = server_answer.substring(data_start, common_greeting_start - 1);
        common_greeting = server_answer.substring(common_greeting_start, personal_greeting_start - 1);
        personal_greeting = server_answer.substring(personal_greeting_start, data_end);
    }

    void parse_greeting_answer() {
        int data_start = server_answer.indexOf("\r\n\r\n") + 4;
        int personal_greeting_start = server_answer.indexOf(";", data_start) + 1;
        int data_end = server_answer.indexOf(";", personal_greeting_start);
        common_greeting = server_answer.substring(data_start, personal_greeting_start - 1);
        personal_greeting = server_answer.substring(personal_greeting_start, data_end);

    }


    bool check_guest(int a[]) {
        String c = "";
        DebugSerial.println("checking guest...");
        for (int i = 0; i < 8; i++) {
            c += (char) a[i];
        }
        request_args = "card=";
        request_page = "card";
        request_args += c;
        build_request();
        String req = request;
        DebugSerial.println(req);
        EthernetClient client;
        if (client.connect(db_server, 80)) {
            client.print(req);
            String ans = "";
            while (!client.available()) {}
            while (client.available()) {
                char q = client.read();
                //DebugSerial.print(q);
                ans += q;
            }
            server_answer = ans;
            DebugSerial.print(server_answer);
            parse_guest_answer();
            client.stop();
            if (guest_authorization == "True")
                return true;
            else
                return false;
        } else {
          DebugSerial.println("Unable to connect to server!");
          need_reset = true;
        }
        need_reset = true;
        return local_db::check_guest(a);
    }


    void request_greetings(int a[]) {
        DebugSerial.println("requesting greetings...");
        String c = "";
        for (int i = 0; i < 8; i++) {
            c += (char) a[i];
        }
        request_page = "greet";
        request_args = "card=";
        request_args += c;
        build_request();
        EthernetClient client;
        String req = request;
        server_answer = "-1";
        if (client.connect(db_server, 80)) {
            //DebugSerial.println(req);
            client.print(req);
            String ans = "";
            while (!client.available()) {}
            while (client.available()) {
                char q = client.read();
                //DebugSerial.print(q);
                ans += q;
            }
            server_answer = ans;
            client.stop();
            parse_greeting_answer();
            DebugSerial.print(common_greeting + " " + personal_greeting);
        } else {
            need_reset = true;
        }
    }
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

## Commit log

2018-04-12 ето важно
2018-07-02 wire connections & arduino scheme
    [pins.fzz]
2018-07-02 save fritz
    [pins.fzz]
2018-07-13 Ethernet shield работает
2018-07-13 get all cards unstable
    [ethernetShield.ino]
2018-09-12 old requests data fix
    [eth.ino]
2018-09-24 новый план платы
2018-10-30 arduino server reset
2018-11-22 fix some strange error. now move = locker_timer update
    [locker.ino]
2018-11-26 геркон
2018-12-03 button fix, tab refact
    [locker.ino]
2019-01-30 Light button
2019-02-05 box scheme dwg
    [компоновка шкаф.dwg]
2019-03-15 another timer. auto mode off
2019-06-07 timers fix
2019-06-11 locker pin changes
2019-11-21 mainboard plan new
    [BoardOutline.gbr, Bottom.gbr, BottomAssy.gbr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]
2019-11-21 plan upd
    [Through.gbr]
2019-11-29 magomia pins
    [Bottom.gbr, BottomAssy.gbr, BottomMask.gbr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]
2019-12-10 new routing
    [BoardOutline.gbr, Bottom.gbr, BottomAssy.gbr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]
2019-12-11 resistors annotation
2020-01-23 new plan
    [Top.gbr]
2020-02-19 input pin size
2022-06-30 README, added some history files
    [Список покупок для новой платы.xlsx]
